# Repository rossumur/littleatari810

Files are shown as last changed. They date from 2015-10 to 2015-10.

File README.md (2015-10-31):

#A Little Atari 810 Disk Drive

**A tiny working model of a retro computing icon offers a blend of nostalgia and sillyness.**

My first computer was an Atari 400. My first disk drive was the magnificent Atari 810. Overwhelmed by a recent wave of nostalgia from playing Zork for the first time in 30 years I have built a working model of an Atari 810 that uses 8Gig microSD cards instead of 5 1/4 inch floppies to emulate up to 8 drives. Maintaining the relative dimensions of drive to media, the model is somewhat smaller than the original.





The original 810 managed 90k per disk and had a volume of about 30,000 cm3. Assuming a 8Gig card the new version can store about 90,000 disks and at 5 cm3 only takes up 0.000167 times as much space. So it is a lot bigger and a lot smaller. Progress eh?

###How it works
The Atari 810 (and subsequent 1050) drives are “smart” serial peripherals. The Atari OS communicates drives, printers, modems and devices using the SIO (“Serial Input/Output”) protocol. SIO devices connected to the Atari with a chunky 13 pin connector.



###Sio
The Atari addresses 5 bytes commands to peripherals by lowering pin 7 (Command) and transmitting 19200 baud asynch serial on pin 5 (Data Out). If the peripheral recognises the command (‘1′,’R’,1,0 for a read from disk 1, for example) it acknowleges the command and responds with data on pin 3 (Data In) at a pokey 19200 baud by default. Pin 10 can supply 50ma of 5v.


###Hardware
The hardware is pretty simple: a LPC1114 microcontroller, a microSD slot, a 3v3 regulator, a led and some caps. I used the 1114 because they are cheap and I had them lying around after building the Wikipedia reader: just about any 3v3 micro with SPI and a UART would also work fine. 





The enclosure is a 3D print from Shapeways. This is the first time I have used them and I have to say I was delighted bt the experience. My inexperience in 3D modeling is evident but Shapeways sent me a lovely collection of little enclosures in various materials. I tried to make it as small as possible and still accomodate the microSD card. Testors enamel completed the look (make sure you mix in some olive with the light tan and cream).


##Software

The microcontroller code emulates up to 8 Atari drives. At power on it checks for a microSD card, mounts a Fat16 or Fat32 file system and scans the card for .ATR and .XFD disk image files commonly used with Atari emulators. It also looks for XEX files which are Atari executables, another emulator mainstay. The code then “inserts”  the BOOT.RUR image into drive 1 and waits for the Atari to start sending commands during bootup.



BOOT.RUR is a UI app written in C and compiled with cc65. Because the drive has no input or display we use this app running on the Atari to select disk images or applications. Cursor keys select the image or xex application, moving off the left or the right edge of the screen will page the list. Keys ‘1’ …’8′ will insert the selected item into drives ‘1’..’8′. The space bar will eject the disk, the return key will boot the selected image or xex. If an xex is selected, the firmware will synthesize a kboot disk image to load and execute it.



It is electrically possible to write an Atari app that can reflash the firmware but so far this is left as an exercise to the reader. The board pinout happens to be the same as a FTDI serial cable so inital firmware downloads can happen through FlashMagic.

As noted earlier, 19200 baud is pretty pokey by modern standards. Other drive and dos vendors came up with various tricks to make the serial run at 38400 or 57600 or beyond. This board supports a common 57600 baud mode so if you tire of the nostalgic thweep-thweep-thweep you can speed things up a bit by using MyPicodos or similar.

There are lots of good commercial and open source emulators and serial cables that are much more complete (and a little more practical) than this one. I am amazed at the continuing innovation on this platform: check out Yoomp and Crownland and compare them to titles released in the 80s.

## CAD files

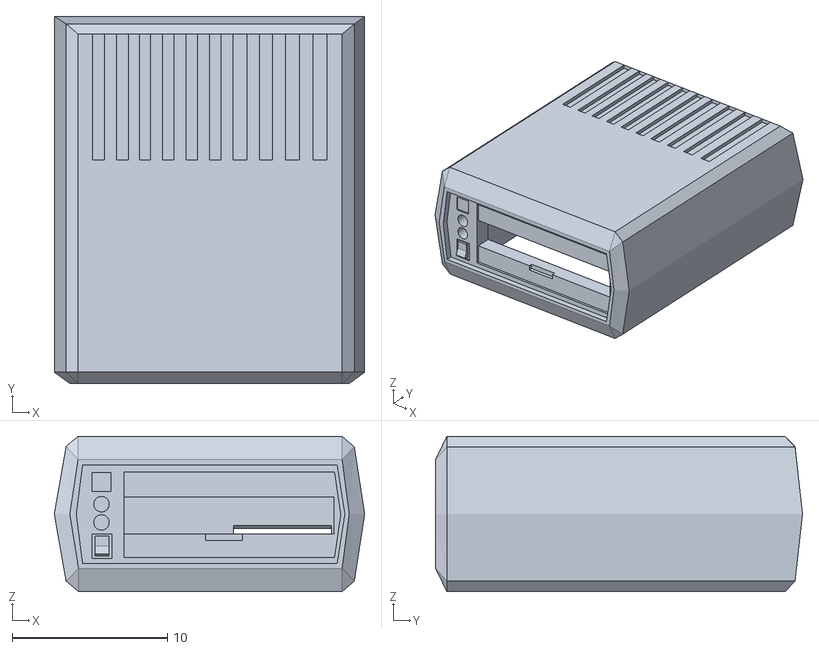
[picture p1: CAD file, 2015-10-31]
a810_model/a810.stl
20.0 x 23.6 x 10.0

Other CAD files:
a810_model/a810.skp

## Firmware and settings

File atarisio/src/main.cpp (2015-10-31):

/*
===============================================================================
 Name        : main.cpp
 Author      : Peter Barrett
 Version     :
 Copyright   : (C) Copyright Peter Barrett
 Description : main definition
===============================================================================
*/

#include "Platform.h"
#include "MMC.h"
#include "Fat32.h"
#include "File.h"
#include "stdarg.h"

//	Minimal semihost
//	Need to force semihosting On in Debug As/Debug Configurations/Debugger/Target Config
int WRITE2(int file, const char *str, int len)
{
	asm volatile (
		".syntax unified\n"
			"push	{r2}\n"
			"push	{r1}\n"
			"push	{r0}\n"
			"movs	r0, #5\n"	// write
			"mov	r1, sp\n"
			"bkpt	0x00ab\n"
			"add	sp, #12\n"
		".syntax divided\n"
	);
}

int _slen =0;
char _sbuffer[128];
int WRITE(int file, const char *str, int len)
{
	while (len--)
	{
		_sbuffer[_slen++] = *str++;
		if (str[-1] == '\n' || _slen == sizeof(_sbuffer))
		{
			WRITE2(file,_sbuffer,_slen);
			_slen = 0;
		}
	}
	return 0;
}

void writesn(const char* s, int n)
{
	if (n)
		WRITE(0,s,n);
}
void writes(const char* s)
{
	if (s)
		WRITE(0,s,strlen(s));
}

void writec(char c)
{
	WRITE(0,&c,1);
}

const char _hex[] = "0123456789ABCDEF";	// Smaller than instructions to add
//	works for bases 2..16
//	hex always unsigned
char HEX(int n)
{
	if (n >= 10)
		return 'A' + n-10;
	return n + '0';
}

char* itoa(int n, char* dst, int base, char padChar, char padCount)
{
    char s[32];
    int i = 0;
    char* r = dst;
    if (base == 16)
    {
    	unsigned int un = n;
		do {
			s[i++] =HEX(un & 0xF);
		} while ((un >>= 4) > 0);
    } else {
	    if (n < 0)
	    {
	    	*r++ = '-';
	        n = -n;
	    }
		do {
			s[i++] = HEX(n % base);	// long divide. eww
		} while ((n /= base) > 0);
    }
    while (i < padCount && i < (int)sizeof(s))
    	s[i++] = padChar;
    while (i--)
    	*r++ = s[i];
    *r++ = 0;
    return dst;
}

extern "C"
int xprintf(const char *fmt, ...)
{
	const char* m = fmt;
	const char *p;
	va_list argp;
	int i;
	char fmtbuf[256];

	va_start(argp, fmt);

	for(p = fmt; *p != '\0'; p++)
	{
		if (*p != '%')
			continue;
		writesn(m,p-m);
		p++;

		char c;
		char padChar = ' ';
		char padCount = 0;
		if (p[0] == '0')
		{
			padChar = '0';
			++p;
		}

		c = p[0];
		while ((c >= '0') && (c <= '9'))
		{
			padCount = padCount*10 + (c - '0');
			c = *++p;
		}

		switch(c)
		{
			case 'c':
				i = va_arg(argp, int);
				writec(i);
				break;

			case 'd':
				i = va_arg(argp, int);
				writes(itoa(i, fmtbuf, 10,padChar, padCount));
				break;

			case 's':
				writes(va_arg(argp, char *));
				break;

			case 'X':
			case 'x':
				i = va_arg(argp, int);
				writes(itoa(i, fmtbuf, 16,padChar, padCount));
				break;

			default:
				writec(c);
				break;
		}
			m = p+1;
	}
	va_end(argp);
	writesn(m,p-m);
	return 0;
}

//==========================================================================
//==========================================================================

#define CLR(_p,_b) _p->MASKED_ACCESS[1 << _b] = 0
#define SET(_p,_b) _p->MASKED_ACCESS[1 << _b] = -1
typedef unsigned char u8;


/* SSP CR1 register */
#define SSPCR1_LBM		(1 << 0)
#define SSPCR1_SSE		(1 << 1)
#define SSPCR1_MS		(1 << 2)
#define SSPCR1_SOD		(1 << 3)

#define SSP_BUFSIZE		16
#define FIFOSIZE		8

void SSPInit( void )
{
  uint8_t i, Dummy;

  LPC_SYSCON->PRESETCTRL |= (0x1<<0);
  LPC_SYSCON->SYSAHBCLKCTRL |= (1<<11);
  LPC_SYSCON->SYSTICKCLKDIV  = 0x02;			/* Divided by 2 */
  LPC_IOCON->PIO0_8 &= ~0x07;	/*  SSP I/O config */
  LPC_IOCON->PIO0_8 |= 0x01;	/* SSP MISO */
  LPC_IOCON->PIO0_9  &= ~0x07;
  LPC_IOCON->PIO0_9 |= 0x01;	/* SSP MOSI */

  LPC_IOCON->SCK_LOC = 0x02;
  LPC_IOCON->PIO0_6 = 0x02;		/* P0.6 function 2 is SSP clock, need to combined with IOCONSCKLOC register setting */

  LPC_IOCON->PIO0_2 &= ~0x07;		/* SSP SSEL is a GPIO pin */

  /* port0, bit 2 is set to GPIO output and high */
  LPC_GPIO0->DIR |= 1 << 2;
  SET(LPC_GPIO0,2);

  LPC_SSP0->CR0 = 0x01C7;	// 8-bit, 12Mhz CPOL = 1, CPHA = 1
	LPC_SSP0->CR0 = 0x00C7;	// 8-bit, 24Mhz CPOL = 1, CPHA = 1

  /* SSPCPSR clock prescale register, master mode, minimum divisor is 0x02 */
  LPC_SSP0->CPSR = 0x2;

  for ( i = 0; i < FIFOSIZE; i++ )
	Dummy = LPC_SSP0->DR;		/* clear the RxFIFO */

  /* Master mode */
  LPC_SSP0->CR1 = SSPCR1_SSE;
}

#define SSPSR_BSY		(1 << 4)

u8 spiTransferByte(u8 data)
{
	LPC_SSP0->DR = data;
	while ( LPC_SSP0->SR & SSPSR_BSY )
		;
	data = LPC_SSP0->DR;
	return data;
}

void SPI_SS_LOW()
{
	CLR(LPC_GPIO0,2);
}
void SPI_SS_HIGH()
{
	SET(LPC_GPIO0,2);
}

u8 SPI_ReceiveByte(u8 data)
{
	LPC_SSP0->DR = data;
	while ( LPC_SSP0->SR & SSPSR_BSY )
		;
	data = LPC_SSP0->DR;
	return data;
}

void SPI_Init() {};
void SPI_Enable() {};
void SPI_Disable() {};

void SPI_Send(u8* data, int len)
{
	while (len--)
		SPI_ReceiveByte(*data++);
}

//	Receives a sector including CRC
void SPI_Receive(u8* data, int len)
{
	while (len--)
		*data++ = SPI_ReceiveByte(0xFF);
	SPI_ReceiveByte(0xFF);
	SPI_ReceiveByte(0xFF);	// Strip CRC
}

void MMC_SS_LOW()
{
	CLR(LPC_GPIO0,2);
}

void MMC_SS_HIGH()
{
	SET(LPC_GPIO0,2);
}

void SetLED(int on)
{
	if (on)
		CLR(LPC_GPIO0,4);
	else
		SET(LPC_GPIO0,4);
}

//==========================================================================
//==========================================================================


#define IER_RBR	0x01
#define IER_THRE	0x02
#define IER_RLS	0x04

#define IIR_PEND	0x01
#define IIR_RLS	0x03
#define IIR_RDA	0x02
#define IIR_CTI	0x06
#define IIR_THRE	0x01

#define LSR_RDR	0x01
#define LSR_OE		0x02
#define LSR_PE		0x04
#define LSR_FE		0x08
#define LSR_BI		0x10
#define LSR_THRE	0x20
#define LSR_TEMT	0x40
#define LSR_RXFE	0x80


void UART_PutChar(int c)
{
	while (!(LPC_UART->LSR & 0x20))
		;
    LPC_UART->THR = c;
}

int UART_GetChar(void)
{
  	if (LPC_UART->LSR & 0x01)
  		return LPC_UART->RBR;
  	return -1;
}

// TODO: insert include files here
void UARTInit(int baudrate)
{
  uint32_t Fdiv;
  uint32_t regVal;

  LPC_IOCON->PIO1_6 &= ~0x07;    /*  UART I/O config */
  LPC_IOCON->PIO1_6 |= 0x01;     /* UART RXD */
  LPC_IOCON->PIO1_7 &= ~0x07;
  LPC_IOCON->PIO1_7 |= 0x01;     /* UART TXD */

  /* Enable UART clock */
  LPC_SYSCON->SYSAHBCLKCTRL |= (1<<12);
  LPC_SYSCON->UARTCLKDIV = 0x1;     /* divided by 1 */

  LPC_UART->LCR = 0x83;             /* 8 bits, no Parity, 1 Stop bit */
  regVal = LPC_SYSCON->UARTCLKDIV;

  Fdiv = (((12000000*LPC_SYSCON->SYSAHBCLKDIV)/regVal)/16)/baudrate ;	/*baud rate */

  LPC_UART->DLM = Fdiv >> 8;
  LPC_UART->DLL = (uint8_t)Fdiv;
  LPC_UART->LCR = 0x03;		/* DLAB = 0 */
  LPC_UART->FCR = 0x07;		/* Enable and reset TX and RX FIFO. */

  /* Read to clear the line status. */
  regVal = LPC_UART->LSR;

  /* Ensure a clean start, no data in either TX or RX FIFO. */
// CodeRed - added parentheses around comparison in operand of &
  while (( LPC_UART->LSR & (LSR_THRE|LSR_TEMT)) != (LSR_THRE|LSR_TEMT) );

  while ( LPC_UART->LSR & LSR_RDR )
	regVal = LPC_UART->RBR;	/* Dump data from RX FIFO */

}

#define SYSPLLCLKSEL_Val      0x00000000	// RC = 0, 1 for crystal
#define SYSPLL_SETUP          1
#define SYSPLLCTRL_Val        0x00000023
#define MAINCLKSEL_Val        0x00000000
#define SYSAHBCLKDIV_Val      0x00000001
#define AHBCLKCTRL_Val        0x0001005F
#define SSP0CLKDIV_Val        0x00000001
#define UARTCLKDIV_Val        0x00000001
#define SSP1CLKDIV_Val        0x00000001

void ClockInit()
{
	LPC_SYSCON->SYSMEMREMAP = 0x03;
	LPC_SYSCON->SYSAHBCLKDIV = 0x01;
	LPC_SYSCON->MAINCLKSEL = 0x00;
	LPC_SYSCON->MAINCLKUEN = 0x00;
	LPC_SYSCON->SYSOSCCTRL = 0x00;
	LPC_SYSCON->SYSAHBCLKCTRL |= 0x5F;

	LPC_SYSCON->MAINCLKSEL    = MAINCLKSEL_Val;     /* Select PLL Clock Output  */
	LPC_SYSCON->MAINCLKUEN    = 0x01;               /* Update MCLK Clock Source */
	LPC_SYSCON->MAINCLKUEN    = 0x00;               /* Toggle Update Register   */
	LPC_SYSCON->MAINCLKUEN    = 0x01;
	while (!(LPC_SYSCON->MAINCLKUEN & 0x01));       /* Wait Until Updated       */

	LPC_SYSCON->SYSAHBCLKDIV  = SYSAHBCLKDIV_Val;
	LPC_SYSCON->SYSAHBCLKCTRL = AHBCLKCTRL_Val;
	LPC_SYSCON->SSP0CLKDIV    = SSP0CLKDIV_Val;
	LPC_SYSCON->UARTCLKDIV    = UARTCLKDIV_Val;
	LPC_SYSCON->SSP1CLKDIV    = SSP1CLKDIV_Val;
}

bool CommandAsserted()
{
	return (LPC_GPIO1->DATA & (1 << 5)) == 0;
}

bool DirectoryP(DirectoryEntry* d, int index, void* ref)
{
	char name[16];
	FAT_Name(name,d);
	printf("> %s\n",name);
	return false;
}

bool _microSDReady = false;

bool microSDReady()
{
	union {
		u32 l[128];
		u8 b[512];
	};
	if (!_microSDReady)
	{
		u8 e = MMC_Init();
		if (e != 0)
			printf("MMC Failed %d\n",e);
		else {
			FAT_Init(b,MMC_ReadSector);
			//FAT_Directory(DirectoryP,b,0);
			_microSDReady = true;
		}
	}
}

void SIOLoop();


volatile uint32_t _ticks;                            /* counts 1ms timeTicks */
extern "C"
void SysTick_Handler(void)
{
	_ticks++;                        /* increment counter necessary in Delay() */
}

void delay(int ms)
{
	uint32_t t = ms + _ticks;
	while (_ticks < t)
		;
}

uint32_t ticks()
{
	return _ticks;
}

int _speed = 19200;
void SetSpeed(int baud)
{
	if (_speed == baud)
		return;
	_speed = baud;
	UARTInit(baud);
}

int main(void)
{
	LPC_GPIO1->DIR |= 1 << 7;
	ClockInit();

	LPC_GPIO0->DIR |= 1 << 4;
	SetLED(1);

	if (SysTick_Config(12000000 / 1000))
		while (1);
	if (!(SysTick->CTRL & (1<<SysTick_CTRL_CLKSOURCE_Msk)))
		LPC_SYSCON->SYSTICKCLKDIV = 0x08;

	UARTInit(19200);
	SSPInit();

	printf("Atari 810 micro\n");
	microSDReady();

	SIOLoop();
	return 0;
}

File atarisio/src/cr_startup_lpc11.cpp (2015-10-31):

//*****************************************************************************
//   +--+       
//   | ++----+   
//   +-++    |  
//     |     |  
//   +-+--+  |   
//   | +--+--+  
//   +----+    Copyright (c) 2009-10 Code Red Technologies Ltd.
//
// Microcontroller Startup code for use with Red Suite
//
// Software License Agreement
// 
// The software is owned by Code Red Technologies and/or its suppliers, and is 
// protected under applicable copyright laws.  All rights are reserved.  Any 
// use in violation of the foregoing restrictions may subject the user to criminal 
// sanctions under applicable laws, as well as to civil liability for the breach 
// of the terms and conditions of this license.
// 
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
//*****************************************************************************
#if defined (__cplusplus)
#ifdef __REDLIB__
#error Redlib does not support C++
#else
//*****************************************************************************
//
// The entry point for the C++ library startup
//
//*****************************************************************************
extern "C" {
	extern void __libc_init_array(void);
}
#endif
#endif

#define WEAK __attribute__ ((weak))
#define ALIAS(f) __attribute__ ((weak, alias (#f)))

// Code Red - if CMSIS is being used, then SystemInit() routine
// will be called by startup code rather than in application's main()
#if defined (__USE_CMSIS)
#include "system_LPC11xx.h"
#endif

//*****************************************************************************
#if defined (__cplusplus)
extern "C" {
#endif

//*****************************************************************************
//
// Forward declaration of the default handlers. These are aliased.
// When the application defines a handler (with the same name), this will 
// automatically take precedence over these weak definitions
//
//*****************************************************************************
     void ResetISR(void);
WEAK void NMI_Handler(void);
WEAK void HardFault_Handler(void);
WEAK void SVCall_Handler(void);
WEAK void PendSV_Handler(void);
WEAK void SysTick_Handler(void);
WEAK void IntDefaultHandler(void);
//*****************************************************************************
//
// Forward declaration of the specific IRQ handlers. These are aliased
// to the IntDefaultHandler, which is a 'forever' loop. When the application
// defines a handler (with the same name), this will automatically take
// precedence over these weak definitions
//
//*****************************************************************************

void I2C_IRQHandler (void) ALIAS(IntDefaultHandler);
void TIMER16_0_IRQHandler (void) ALIAS(IntDefaultHandler);
void TIMER16_1_IRQHandler (void) ALIAS(IntDefaultHandler);
void TIMER32_0_IRQHandler (void) ALIAS(IntDefaultHandler);
void TIMER32_1_IRQHandler (void) ALIAS(IntDefaultHandler);
void SSP_IRQHandler (void) ALIAS(IntDefaultHandler);
void UART_IRQHandler (void) ALIAS(IntDefaultHandler);
void USB_IRQHandler (void) ALIAS(IntDefaultHandler);
void USB_FIQHandler (void) ALIAS(IntDefaultHandler);
void ADC_IRQHandler (void) ALIAS(IntDefaultHandler);
void WDT_IRQHandler (void) ALIAS(IntDefaultHandler);
void BOD_IRQHandler (void) ALIAS(IntDefaultHandler);
void FMC_IRQHandler (void) ALIAS(IntDefaultHandler);
void PIOINT3_IRQHandler (void) ALIAS(IntDefaultHandler);
void PIOINT2_IRQHandler (void) ALIAS(IntDefaultHandler);
void PIOINT1_IRQHandler (void) ALIAS(IntDefaultHandler);
void PIOINT0_IRQHandler (void) ALIAS(IntDefaultHandler);
void WAKEUP_IRQHandler  (void) ALIAS(IntDefaultHandler);

//*****************************************************************************
//
// The entry point for the application.
// __main() is the entry point for redlib based applications
// main() is the entry point for newlib based applications
//
//*****************************************************************************
//
// The entry point for the application.
// __main() is the entry point for Redlib based applications
// main() is the entry point for Newlib based applications
//
//*****************************************************************************
#if defined (__REDLIB__)
extern void __main(void);
#endif
extern int main(void);
//*****************************************************************************
//
// External declaration for the pointer to the stack top from the Linker Script
//
//*****************************************************************************
extern void _vStackTop(void);

//*****************************************************************************
#if defined (__cplusplus)
} // extern "C"
#endif
//*****************************************************************************
//
// The vector table.  Note that the proper constructs must be placed on this to
// ensure that it ends up at physical address 0x0000.0000.
//
//*****************************************************************************
extern void (* const g_pfnVectors[])(void);
__attribute__ ((section(".isr_vector")))
void (* const g_pfnVectors[])(void) = {
    &_vStackTop,		    				// The initial stack pointer
    ResetISR,                               // The reset handler
    NMI_Handler,                            // The NMI handler
    HardFault_Handler,                      // The hard fault handler
    0,                      				// Reserved
    0,                      				// Reserved
    0,                      				// Reserved
    0,                                      // Reserved
    0,                                      // Reserved
    0,                                      // Reserved
    0,                                      // Reserved
    SVCall_Handler,                      	// SVCall handler
    0,                      				// Reserved
    0,                                      // Reserved
    PendSV_Handler,                      	// The PendSV handler
    SysTick_Handler,                      	// The SysTick handler
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
